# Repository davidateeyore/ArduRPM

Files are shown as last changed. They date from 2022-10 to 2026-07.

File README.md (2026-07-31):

# ArduRPM
using my ArduPSU board as a RPM counter for my minilathe; so far the setup has been successful, but the code for the counter doesn't go back to zero when the lathe spindle stops (should display "0 RPM"). 
I am working on some more solid code for this..
This code is an early version; the later version currently in the counter is buried somewhere on the workshop lappie...
It appears that the conventional Arduino libraries and methods using timers and interrupts have issues at slow speeds and high speeds..next approach is to do it in AVR code directly, rather than Arduino code.
Still the 3D printed case has worked out quite well, with a RJ style socket for the sensor head and a DC power socket for the 5V needed to run the unit.
The ARDUpsu board is being reworked to allow other applications on the atMEGA328 with the 8x2 OLED display..

The STL files for the ArduRPM box with lid. I printed it in PLA+ on a Creality Ender 5 printer without any problems..
UPDATE (of sorts!)
I have found an article suggesting using a 60 slot opto-interruper wheel which could improve the performance: openSCADded a suitable design and will test it with some better arduino code (60 pulses detected equauls 1 rev per minute) and just do a frequency count for 1 second then divide by 60 and display RPM.. just need to fix the code.. 

Later(10MAR2024) the positioning of the optointerrupter is critical, there isn't much room at the head end of the minilathe. Also, at speed, the pulse shaping is rather crappy. may need to put a buffer in place with input pulldown.. 

17MAY2024 .. the bracket for the optointerrupter needs replacing; a piece of aluminium angle suitable milled and drilled will help along with the aforemention pulse shaping mods.. 

25AUG2024 .. the bracket has been put on hold, due to Medical circs.. I have to clear the shed out to get safely to my machine tools!

31JUL2026 .. Maybe an ESP32 may be better for handling the crappy pulses..

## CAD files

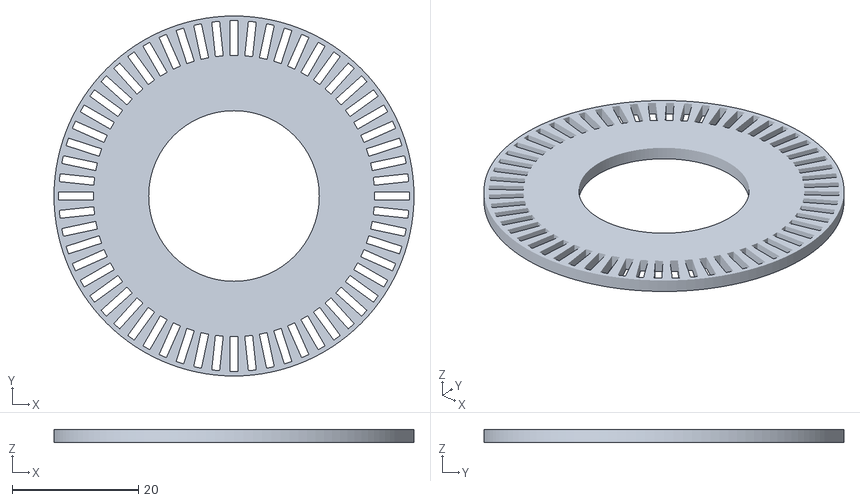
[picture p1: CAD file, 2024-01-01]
dt-multislot-wheel.stl
57.0 x 57.0 x 2.00

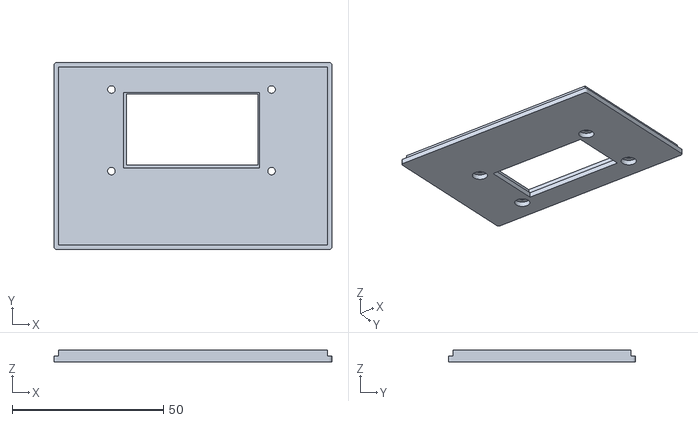
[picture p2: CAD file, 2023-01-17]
LatheRPM-lid-1-2.stl
92.0 x 62.0 x 4.00

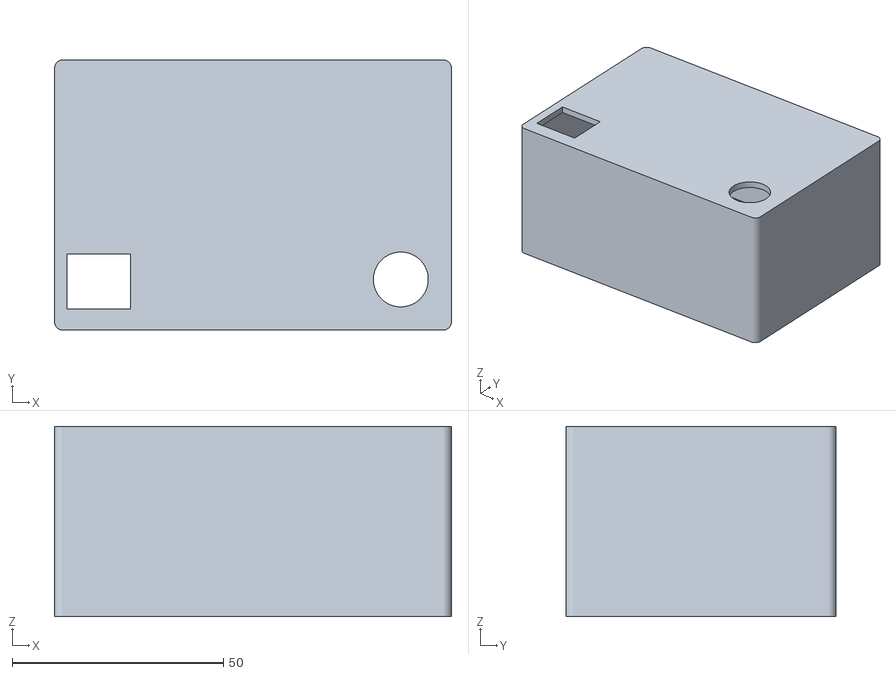
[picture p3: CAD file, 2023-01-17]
LatheRPM-casebox-1-1.stl
94.0 x 64.0 x 45.0

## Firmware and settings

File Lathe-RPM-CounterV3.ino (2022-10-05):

// Lathe-RPM-CounterV3.ino
// dt 15DEC2021
// more stuff dt 02DEC2021
// more changes dt 10DEC2021
// input from slotted disc/optointerrupter mounted
// on MiniLathe tailstock spindle
// to dt ArduPSU PCB driving 8x2 OLED display
// uses atMEGA328 (UNO like)
// some code based on: www.instructables.com/id/Arduino-Based-Optical-Tachometer/  
//
// The interrupt arrangement do not appear to work with my test setup
// so I will try a different counting approach..
// =======================
// I/O Pin definitions    
// =======================
#include <Adafruit_CharacterOLED.h>
#include <Wire.h>
#include <FreqMeasure.h>
#include <stdlib.h>

// #define ledPin 13

const byte ledPin = 13;
int sensorPin = 4;  // this library requires pin "D8" for UNO, bur we are using D8,
// so "D4 (Pin 6)" will have to replace D8 Pin 14....
// initialize the library with the OLED hardware 
// version OLED_Vx and numbers of the interface pins. 
// OLED_V1 = older, OLED_V2 = newer. If 2 doesn't work try 1 ;)
// Adafruit_CharacterOLED CounterOLED(OLED_V2, 6, 7, 8, 9, 10, 11, 12); // testing
Adafruit_CharacterOLED CounterOLED(OLED_V2, 12, 11, 10, 4, 7, 6, 5); // using PCB
// pin D8 changed to pin D4
// rs, rw, enable, d4, d5, d6, d7
//**********************************
//
//**********************************
void setup() {
  // put your setup code here, to run once:
  // initialise OLED
  // rpm = 1234; // just a display test value..
  pinMode(ledPin, OUTPUT);      // sets the digital pin as output
  //pinMode(sensorPin, INPUT);
  CounterOLED.begin(8, 2);
  CounterOLED.clear(); 
  CounterOLED.print("LatheRPM");
  CounterOLED.setCursor(0,1);  // line 2 
  CounterOLED.print("dtV0.58");
  delay(2000); // so that I can see the init and version!
  CounterOLED.clear(); // flush screen..
  // setup counter
  FreqMeasure.begin();
  // 3 blinks to make sure arduino is working.. 
  digitalWrite(ledPin, HIGH);
  delay(100);
  digitalWrite(ledPin, LOW);
  delay(100);  
  digitalWrite(ledPin, HIGH);
  delay(100);
  digitalWrite(ledPin, LOW); 
  delay(100); 
  digitalWrite(ledPin, HIGH);
  delay(100);
  digitalWrite(ledPin, LOW);  
  // 
}

double sum=0;
int count=0;

void loop() {
  // put your main code here, to run repeatedly:
  // code for reading optointerrupter and RPM display
  //

  CounterOLED.setCursor(0,0);  // line 1
  CounterOLED.print("My Lathe");
  CounterOLED.setCursor(0,1);  // line 2  
  CounterOLED.print("RPM=");
  //delay(200);
  
  //delay(200);
  CounterOLED.setCursor(4,1);
  if (FreqMeasure.available()) {
    // average several reading together
    sum = sum + FreqMeasure.read();
    count = count + 1;
    if (count > 30) {
      float frequency = FreqMeasure.countToFrequency(sum / count);
      CounterOLED.setCursor(4,1);
      int rpm = ((frequency * 60)/10);  // Hz to RPM divided by 10 - opto 
      // produces 10 pulses per revolution
      CounterOLED.print(rpm);
      
      CounterOLED.print("    "); // flush previous reading..
      sum = 0;
      count = 0;
    }
  }
  // Update RPM every second
  //delay(1000);
  //rpm = int(pulseCount/10); // 10 slots on disc wheel..
  // now display rpm!
  //CounterOLED.print(rpm);
  //delay(1000);  // just to see what changes..
  //
  //
}
